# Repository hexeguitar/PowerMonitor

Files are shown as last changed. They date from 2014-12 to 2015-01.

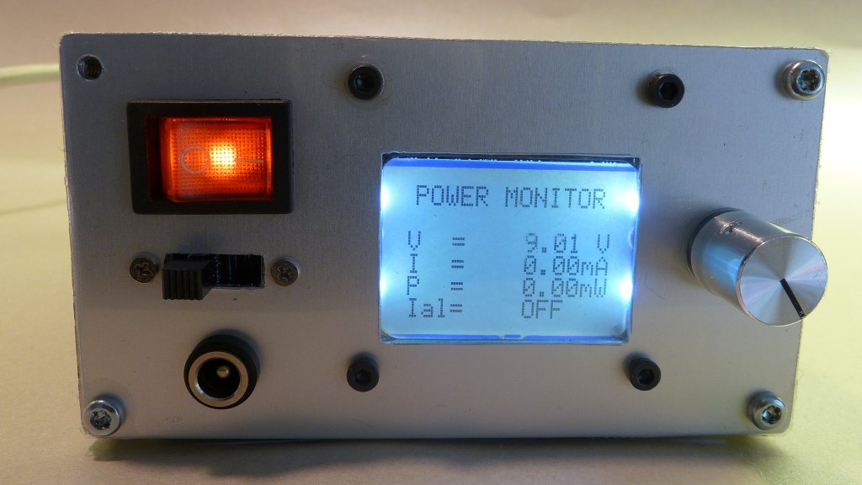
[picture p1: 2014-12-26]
Pics/pmon7.jpg

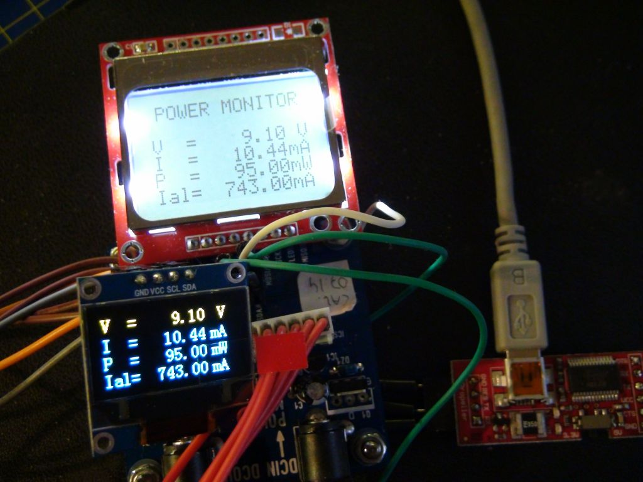
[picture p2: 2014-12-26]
Pics/pmon5.jpg

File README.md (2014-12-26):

#POWER MONITOR

INA219 + PIC24F16KA101 DC voltage, current and power measurement module.

Power Monitor is a small module designed to be placed between the DC power supply and the load. 
It measures the bus voltage, current drawn by the load and calculates the total power consumption.
The results are displayed on a small 0.96" OLED display (SSD1306 controlled via I2C) or
on a SPI controlled PCD5844 (Nokia 5110) LCD.

In addition, the module has an overcurrent alarm feature. A pot is used to set the threshold value (0-1A).
If the measured current exceedes the set threshold, the module will signal it with a pulsing piezo buzzer sound
and a blinking current value on the display.

Since the device was originally designed as an aid while developing guitar effect pedals 
the DC jacks polarity is center negative and the measured current range is set to 0 - 1A.

The device automatically detects if the power jacks are reversed (power applied to the DC out jack)
and kindly asks you to 

###Specs:
- maximum input/bus voltage: 26V DC (INA219B max rating)
- voltage measurement resolution: 10mV 
- measured current range: 0 - 1A (can be changed, refer to the INA219 datasheet)
- current measurement resolution: 50µA
- I alarm range: 0 - 1A, setting the pot to max switches the alarm function OFF
- low dropout reverse supply polarity included
- DC in, DC out jacks: 5.5/2.1mm, center negative
- optional INA219 recalibration mode via UART

###Data outputs:
- SSD1206 OLED display (software I2C)
- PCD8544 LCD (SPI)
- UART (9600 baud)

###Extras:
- hardware I2C pin header
- software I2C pin header (used to driver the OLED display)
- hardware SPI pin header (used to drive the PCD8544 LCD display)
- hardware UART pin header
- ICSP programming pin header
- logic input RB1 

###UART (9600 baud 8b 1Sb NP) commands
NORMAL MODE:

- **lcd**     data output format, copy of the LCD display
- **raw**     data output format, raw numbers separated by semicolons 
- **stop**    stops updating the data via UART
- **start**   start/resume the data update in 1 second intervals
- **rstcnt**  resets the measurement counter to 0
- **getcnt**  returns the actual masurement counter value
- **calrst**  resets the INA219 calibration constant to theoretic calculated stock value (8192)
- **recal**   INA219 secodary recalibration mode used to increase the precision. Requires a separate at least 4.5 digit mA/A meter as a reference
- **getcal**  return the actual INA219 calibration constant value
- **y**       yep! I confirm
- **n**       no, thanks.

RECAL MODE:

- **xxxx.xx** waits for the reference current value (xxxx.xx[mA] format)
- **exit**    cancel the calibration and return to NORMAL mode

The PCB is designed as a small PIC24F16KA101 dev board and could be used to develop many new projects.
I2C, SPI and UART pins are provided as pin headers for easy interfacing.

License: design is released under

Creative Commons NonCommercial-ShareAlike

CC BY-NC-SA



Please contact me for commercial opportunities. 

(c) 07.2014 Piotr Zapart
www.hexeguitar.com

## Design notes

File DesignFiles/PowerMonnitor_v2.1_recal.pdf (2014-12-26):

Project Name:

Author:

## POWER MONITOR

PIOTR ZAPART
www.hexeguitar.com

PIC24F16KA101 + INA219
mini dev board

License:

Date:
05-07.2014

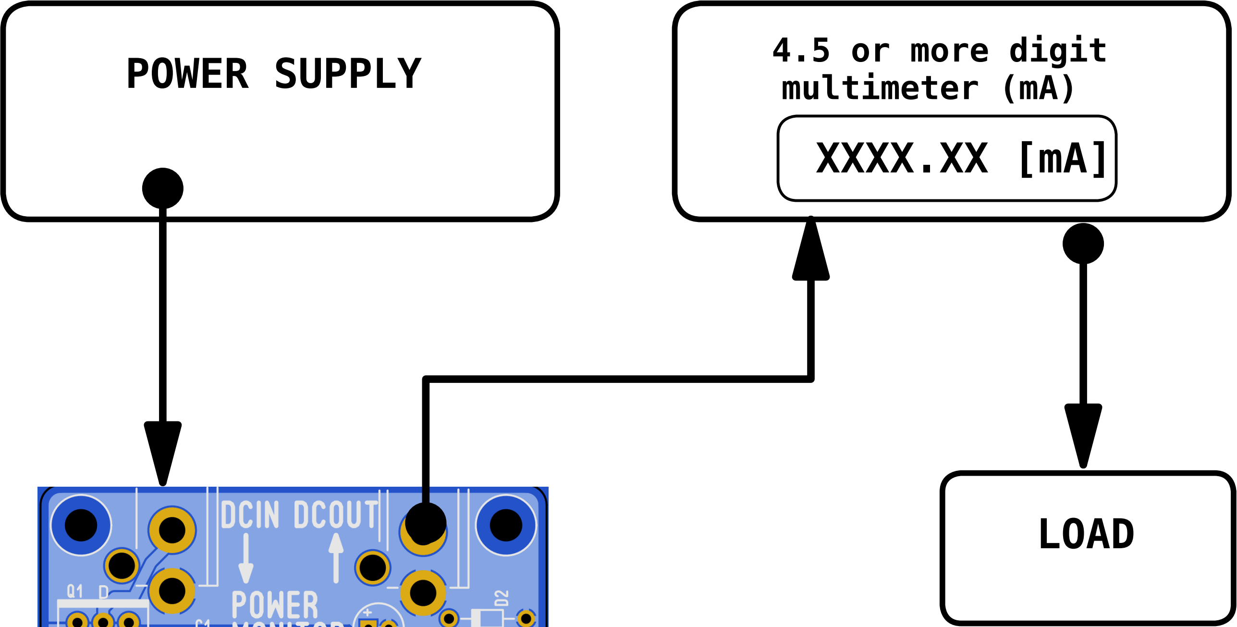
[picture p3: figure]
POWER SUPPLY; LOAD; 4.5 or more digit multimeter (mA) XXXX.XX [mA]

## UART->USB adapter

TX&RX crossed!

PC+serial port terminal

1. Connect the power supply (5-26VDC) to the DCIN input.

### 2. A 4.5 or more digit multimeter (miliAmpmeter) should be

used as a reference. Connect it between the DCOUT and the LOAD.

3. Connect ther UART output (9600baus, 8bit, 1 stop bit,
no parity) to the PC, use an UART/USB adapter if your PC doesn't have the serial port.
4. Use a serial port terminal program to perform the procedure.

### 5. Send the command: "recal" to start the procedure

6. Read the reference current measured with the multimeter.

### 7. Input the refernce current in format xxxx.xx

the value is in [mA].

8. A new calibration constant will be calculated and shown.

### 9. Send "y" to save the new constant in EEPROM or "n"

to cancel the operation.

### 10. You can cancel the recalibration procedure at any time

by sending the command "exit"

## INA219 recalibration procedure via UART

optional way to increase the measurement precision

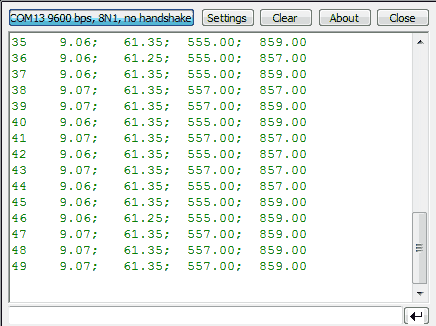
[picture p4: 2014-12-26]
Pics/pmon_uart_raw.png

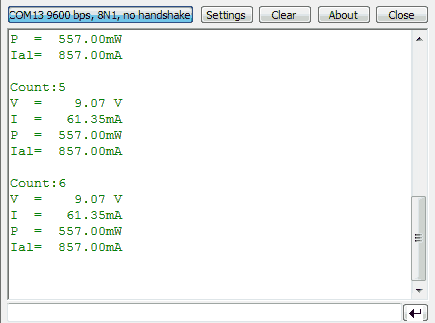
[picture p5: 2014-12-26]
Pics/pmon_uart_lcd.png

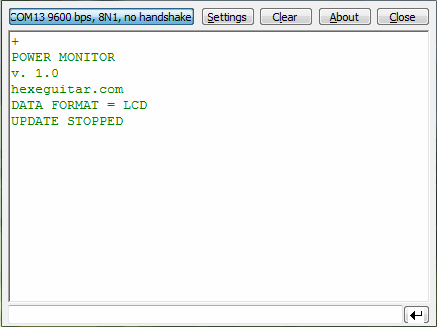
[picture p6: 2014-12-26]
Pics/pmon_uart_startup.png

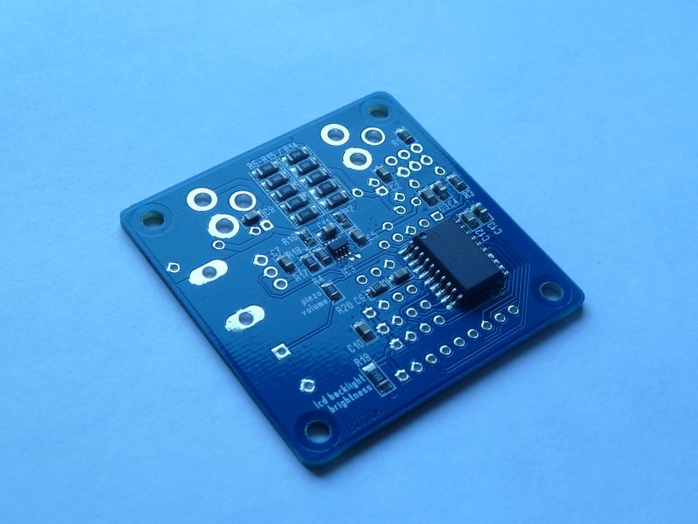
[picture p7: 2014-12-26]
Pics/pmon9.jpg

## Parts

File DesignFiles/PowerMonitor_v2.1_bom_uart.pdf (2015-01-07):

Project Name:

Author:

# POWER MONITOR

## PIOTR ZAPART www.hexeguitar.com

PIC24F16KA101 + INA219
mini dev board

License:

Date:
05-07.2014

BOM:

C1 = 100n (50V 0805)
C2 = 100n (50V 0805)
C3 = 10µ (50V RM2.5/5mm)
C4 = 100n (50V 0805)
C5 = 10µ (16V 0805 MLCC)
C6 = 100n (50V 0805)
C7 = 100n (50V 0805)
C8 = 1µ (0805 16V -do not mount) C9 = 10µ (50V RM2.5/5mm)
C10 = 100n (50V 0805)
C11 = 100n (50V 0805)
C12 = 10µ (16V 0805 MLCC)

CN1 = DCIN (DC Jack 5.5/2.1mm)
CN2 = ICSP (5pin Microchip ICSP) CN3 = DCOUT (DC Jack 5.5/2.1mm)
CN4 = OLED_I2C (4 pin header RM2.54) CN5 = I2C (4 pin header RM2.54)
CN6 = UART (4 pin header RM2.54)
CN7 = SPI/5110 LCD (9 pin header RM2.54) CN8 = RB1 (3 pin header RM2.54)
CN9 = UART (4 pin header RM2.54)

R1 = 100k (0805)
R2 = 470R (0805 1% 0.125W)
R3 = 10k (0805 1% 0.125W)
R4 = 0.1R 1W 0.1% (1206 0.25W 0.5%) R5 = 1R 0.5% (1206 0.25W 0.5%)
R6 = 1R 0.5% (1206 0.25W 0.5%)
R7 = 1R 0.5% (1206 0.25W 0.5%)
R8 = 1R 0.5% (1206 0.25W 0.5%) R9 = 1R 0.5% (1206 0.25W 0.5%) R10 = 1R 0.5% (1206 0.25W 0.5%) R11 = 1R 0.5% (1206 0.25W 0.5%) R12 = 1R 0.5% (1206 0.25W 0.5%) R13 = 1R 0.5% (1206 0.25W 0.5%) R14 = 1R 0.5% (1206 0.25W 0.5%) R15 = 0R(10R) (0805 1% 0.125W) R16 = 0R(10R) (0805 1% 0.125W) R17 = 2k2 (0805 1% 0.125W)
R18 = 2k2 (0805 1% 0.125W) R19 = 47R (1206 0.25W )
R20 = 10k (0805 1% 0.125W)

D1 = 1N4007
D2 = 1N4007

DZ1 = 9V1 (9.1V Zener Diode THT)

IC1 = L78L33 (TO92 3.3V Vreg) IC2 = PIC24F16KA101
IC3 = INA219B SOT23-8

LCD1 = 128x64 i2C SSD1306 OLED
LCD2 = Nokia5110 PCD8544 LCD (SPI)

SPK1 = Piezo buzzer (2.4kHz 12mm RM6.5mm)

P1 = 10k-50k LIN (ALPS RK09L114001T)

Q1 = AP4435GJ (PMOS -30V 21mOhm)

UART (9600 baud 8b 1Sb NP) commands
NORMAL MODE:
lcd | data output format, copy of the LCD display
raw | data output format, raw numbers separated by semicolons
stop | stops updating the data via UART
start | start/resume the data update in 1 second intervals
rstcnt resets the measurement counter to 0
getcnt returns the actual masurement counter value
calrst resets the INA219 calibration constant to theoretic calculated stock value (8192)
recal | INA219 secodary recalibration mode used to increase the precision.
| Requires a separate at least 4.5 digit mA/A meter as a reference.
getcal return the actual INA219 calibration constant value
y | yep! I confirm
n | no, thanks.

RECAL MODE:
xxxx.xx waits for the reference current value (xxxx.xx[mA] format) exit cancel the calibration and return to NORMAL mode

C13 = 100n (50V 0805)

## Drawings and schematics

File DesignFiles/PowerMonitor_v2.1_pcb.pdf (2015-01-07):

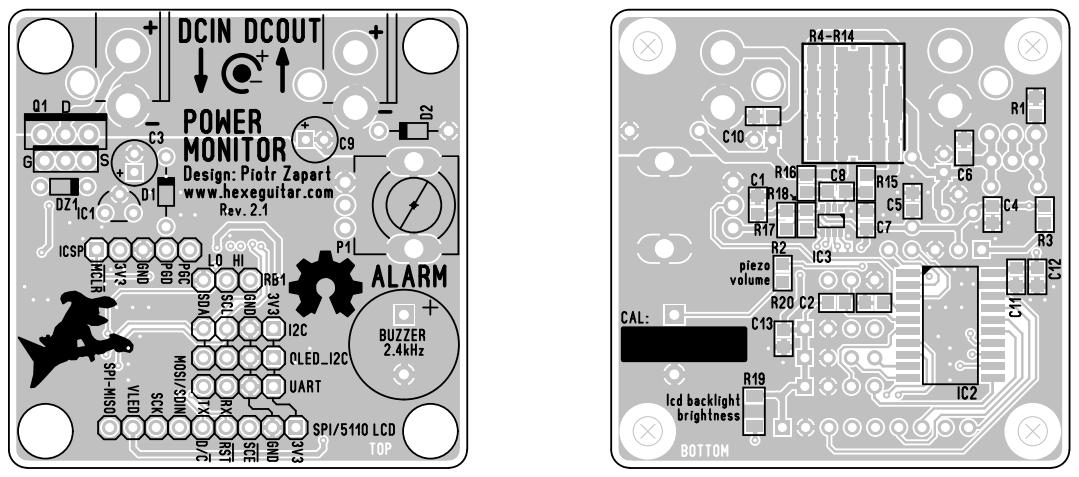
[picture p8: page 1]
Author:; License:; Date: 05-07.2014

Project Name:
POWER MONITOR
PIC24F16KA101 + INA219
mini dev board
PIOTR ZAPART
www.hexeguitar.com

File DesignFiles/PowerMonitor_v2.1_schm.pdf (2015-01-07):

CN1

## DCIN

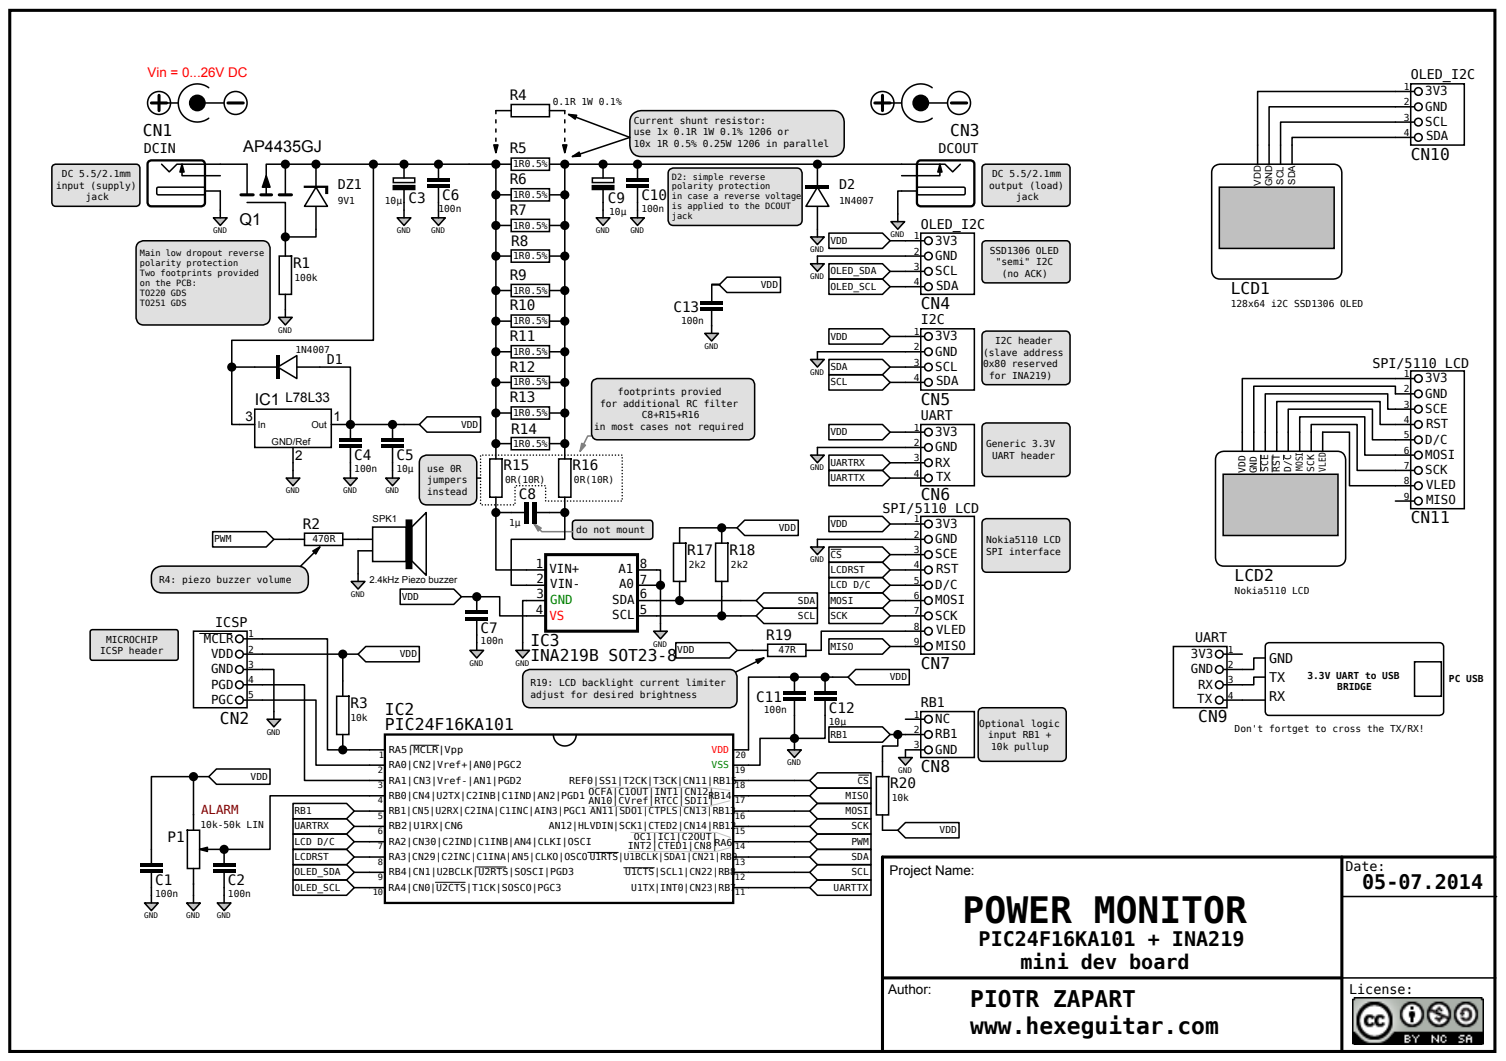
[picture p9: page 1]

in case a reverse voltage
is applied to the DCOUT

Main low dropout reverse
polarity protection
Two footprints provided
on the PCB:
TO220 GDS
TO251 GDS

footprints provied
for additional RC filter

in most cases not required

Don't fortget to cross the TX/RX!

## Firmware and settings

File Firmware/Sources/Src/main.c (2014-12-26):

/*
**                        POWER MONITOR
**                   (c) 07.2014 Piotr Zapart
**                      www.hexeguitar.com
**
**********************************************************************/

#include <xc.h>


_FOSCSEL(FNOSC_FRCDIV);			// Select 8 MHz FRC oscillator with divide-by-N (FRCDIV)


_FOSC (	FCKSM_CSECMD & 			// Enable Clock Switching
	OSCIOFNC_ON &			// Clock output = digital IO
	POSCMOD_NONE );			// Primay osc disable

_FWDT (	FWDTEN_OFF &			//watchdog on
	FWPSA_PR32 &			//prescaler /32
	WDTPS_PS2048 );			//postscaler /2048

_FPOR ( BOREN_BOR3 &                    //Brown-out Reset enabled in hardware; SBOREN bit disabled
        PWRTEN_ON &                     //PWRT enabled
        BORV_V27                        //Brown-out Reset set to Highest Voltage (2.7V)
                    );
_FDS    (DSWDTEN_OFF);                   //DSWDT disabled

_FICD (ICS_PGx2);

#include "platform.h"


// ################ FUNCTION DEFINITIONS ##################


/// ### Ialarm calculation ###
uint16_t calc_Ialarm(uint16_t input, uint16_t max)
{
    uint32_t temp32;
    uint16_t temp16;

    temp32 = __builtin_muluu(input,input);      //square for better resolutionx
    temp16 = (uint16_t)(temp32>>10);            //settings

    temp32 = __builtin_muluu(temp16,(max+5));   //scale it 0...IalMax+5
    temp16 = (uint16_t)((temp32>>10)+1);
    
    if (temp16 > max)   return 0;       //Ial = 0 -> alarm shutdown
   // else                return myround((float)temp16);
    else                return temp16;
}

void wait8ms(unsigned int cnt)
{
	delay8ms = cnt;
	while(delay8ms);
}
// ################## DISPLAY DATA ##########################
void display_data(cal_modes cal_mode)
{
        char temp_txt[9];
	static uint8_t blinker;
	blinker++;
        //convert and format float values to ascii    
        f_to_txt(bus_voltage_V,V_txt);
        f_to_txt(current_mA,I_txt);
        
        //convert and format int values to ascii
        int_to_txt(power_mW,4,P_txt);
        int_to_txt(Ialarm,4,Ial_txt);

        switch(cal_mode)
        {
            case CL_OFF:
                      //update OLED display
                        OLED_char_F8x16(0,0,vbus_txt,NORMAL);
                        OLED_char_F8x16(100,0,volts_txt,NORMAL);
                        OLED_char_F8x16(32,0,V_txt,NORMAL);
                        OLED_char_F8x16(0,2,current_txt,NORMAL);
                        OLED_char_F8x16(32,2,I_txt,(status.alarm&&(blinker&_BV(0))));
                        OLED_char_F8x16(100,2,mA_txt,NORMAL);
                        OLED_char_F8x16(0,4,power_txt,NORMAL);
                        OLED_char_F8x16(32,4,P_txt,NORMAL);
                        OLED_char_F8x16(100,4,mW_txt,NORMAL);
                        OLED_char_F8x16(0,6,curr_al_txt,NORMAL);
                        if (status.alarm_sdown)
                        {
                            OLED_char_F8x16(32,6,off_txt,NORMAL);
                            OLED_char_F8x16(100,6,"  ",NORMAL);
                        }
                        else
                        {
                            OLED_char_F8x16(32,6,Ial_txt,NORMAL);
                            OLED_char_F8x16(100,6,mA_txt,NORMAL);
                        }
                        //update 5110 display
                        LCD5110_write_string(3,0,"POWER MONITOR",DISP_NORMAL);
                        LCD5110_write_string(0,2,vbus_txt,DISP_NORMAL);
                        LCD5110_write_string(72,2,volts_txt,DISP_NORMAL);
                        LCD5110_write_string(24,2,V_txt,DISP_NORMAL);
                        LCD5110_write_string(0,3,current_txt,DISP_NORMAL);
                        LCD5110_write_string(24,3,I_txt,(status.alarm&&(blinker&_BV(0))));
                        LCD5110_write_string(72,3,mA_txt,DISP_NORMAL);
                        LCD5110_write_string(0,4,power_txt,DISP_NORMAL);
                        LCD5110_write_string(24,4,P_txt,DISP_NORMAL);
                        LCD5110_write_string(72,4,mW_txt,DISP_NORMAL);
                        LCD5110_write_string(0,5,curr_al_txt,DISP_NORMAL);
                        if (status.alarm_sdown)
                        {
                            LCD5110_write_string(24,5,off_txt,DISP_NORMAL);
                        }
                        else
                        {
                            LCD5110_write_string(24,5,Ial_txt,DISP_NORMAL);
                            LCD5110_write_string(72,5,mA_txt,DISP_NORMAL);
                        }
                        break;
            case CL_RST:
                        
            case CL_RST_CONFIRM:
                        OLED_char_F8x16(16,0,cal_txt,NORMAL);
                        OLED_char_F8x16(32,2,rst_txt,NORMAL);
                        OLED_char_F8x16(0,6,save_txt,NORMAL);
                        OLED_char_F8x16(48,6,yn_txt,NORMAL);
                        LCD5110_write_string(8,0,cal_txt,DISP_NORMAL);
                        LCD5110_write_string(18,2,rst_txt,DISP_NORMAL);
                        LCD5110_write_string(0,5,save_txt,DISP_NORMAL);
                        LCD5110_write_string(30,5,yn_txt,DISP_NORMAL);
                        break;
            case RCL_ON:
                        OLED_char_F8x16(16,0,cal_txt,NORMAL);
                        OLED_char_F8x16(0,2,current_txt,NORMAL);
                        OLED_char_F8x16(32,2,I_txt,NORMAL);
                        OLED_char_F8x16(100,2,mA_txt,NORMAL);
                        OLED_char_F8x16(0,4,iref_txt,NORMAL);
                        OLED_char_F8x16(32,4,he_txt,(blinker&_BV(0)));
                        OLED_char_F8x16(100,4,mA_txt,NORMAL);
                        LCD5110_write_string(12,0,cal_txt,DISP_NORMAL);
                        LCD5110_write_string(0,2,current_txt,DISP_NORMAL);
                        LCD5110_write_string(24,2,I_txt,NORMAL);
                        LCD5110_write_string(72,2,mA_txt,DISP_NORMAL);
                        LCD5110_write_string(0,3,iref_txt,DISP_NORMAL);
                        LCD5110_write_string(24,3,he_txt,(blinker&_BV(0)));
                        LCD5110_write_string(72,3,mA_txt,DISP_NORMAL);
                        break;
            case RCL_CONFIRM:
                        
                        f_to_txt(ref_current_mA,temp_txt);
              
                        OLED_char_F8x16(16,0,cal_txt,NORMAL);

                        OLED_char_F8x16(0,2,current_txt,NORMAL);
                        OLED_char_F8x16(32,2,I_txt,NORMAL);
                        OLED_char_F8x16(100,2,mA_txt,NORMAL);
                        OLED_char_F8x16(0,4,iref_txt,NORMAL);
                        OLED_char_F8x16(32,4,temp_txt,NORMAL);
                        OLED_char_F8x16(100,4,mA_txt,NORMAL);
                        OLED_char_F8x16(0,6,save_txt,NORMAL);
                        OLED_char_F8x16(48,6,yn_txt,NORMAL);

                        LCD5110_write_string(12,0,cal_txt,DISP_NORMAL);
                        LCD5110_write_string(0,2,current_txt,DISP_NORMAL);
                        LCD5110_write_string(24,2,I_txt,NORMAL);
                        LCD5110_write_string(72,2,mA_txt,DISP_NORMAL);
                        LCD5110_write_string(0,3,iref_txt,DISP_NORMAL);
                        LCD5110_write_string(24,3,temp_txt,NORMAL);
                        LCD5110_write_string(72,3,mA_txt,DISP_NORMAL);
                        LCD5110_write_string(0,5,save_txt,DISP_NORMAL);
                        LCD5110_write_string(30,5,yn_txt,DISP_NORMAL);
                        break;          
        }       
}
// ################## DISPLAY WARNING #######################
void display_warning(void)
{
	static uint8_t blinker;
	blinker++;
	OLED_char_F8x16(20,0,warning1_txt,NORMAL);
	OLED_char_F8x16(32,2,warning2_txt,(blinker&_BV(0)));
	OLED_char_F8x16(44,4,warning3_txt,NORMAL);
	OLED_char_F8x16(0,6,warning4_txt,NORMAL);
        OLED_char_F8x16(32,6,warning5_txt,NORMAL);

        LCD5110_write_string(8,0,warning1_txt,DISP_NORMAL);
        LCD5110_write_string(15,2,warning2_txt,(blinker&_BV(0)));
        LCD5110_write_string(13,4,warning3_txt,DISP_NORMAL);
        LCD5110_write_string(49,4,warning4_txt,DISP_NORMAL);
        LCD5110_write_string(8,5,warning5_txt,DISP_NORMAL);

}
// ################## SEND RESULTS VIA UART #######################
uart_data_format get_udata_format(void)
{
    uart1.setup_eep =  eeRead(UART_SETUP_EEP_ADDR);

    if (uart1.setup_eep&_BV(U1_DISP_MODE))
    {
        UART1_send_string_ln(format_raw_txt);
        return RAW;
    }
    else
    {
        UART1_send_string_ln(format_lcd_txt);
        return LCD;
    }
}
void update_uart(uart_data_format mode)
{
    char uart_cnt_txt[9];

    itoa(uart_cnt_txt, (int)uart1.counter, 10);

    uart1.counter++;
    switch(mode)
    {
        case OFF:   break;
        case LCD:
                    UART1_send_string("Count:");
                    UART1_send_string_ln(uart_cnt_txt);
                    UART1_send_string(vbus_txt);
                    UART1_send_string(V_txt);
                    UART1_send_string_ln(volts_txt);
                    UART1_send_string(current_txt);
                    UART1_send_string(I_txt);
                    UART1_send_string_ln(mA_txt);
                    UART1_send_string(power_txt);
                    UART1_send_string(P_txt);
                    UART1_send_string_ln(mW_txt);
                    UART1_send_string(curr_al_txt);
                    if (status.alarm_sdown)
                    {
                        UART1_send_string(off_txt);
                    }
                    else
                    {
                        UART1_send_string(Ial_txt);
                        UART1_send_string(mA_txt);
                    }
                    UART1_send_string("\n");
                    break;
        case RAW:
                    UART1_send_string(uart_cnt_txt);
                    UART1_send_string(V_txt);
                    UART1_send_string(sep_char);
                    UART1_send_string(I_txt);
                    UART1_send_string(sep_char);
                    UART1_send_string(P_txt);
                    UART1_send_string(sep_char);
                    if (status.alarm_sdown)
                    {
                        UART1_send_string(off_txt);
                    }
                    else
                    {
                        UART1_send_string(Ial_txt);
                    }
                    break;
    }
}

// ### send reverse power jacks warning ####
void uart_warning(void)
{
    UART1_send_string(warning1_txt);
    UART1_send_string(" ");
    UART1_send_string_ln(warning2_txt);
    UART1_send_string(warning3_txt);
    UART1_send_string(" ");
    UART1_send_string(warning4_txt);
    UART1_send_string(" ");
    UART1_send_string_ln(warning5_txt);
}
// ### decode incoming UART commands ###
uint8_t decode_char(uint16_t err_data)
{
    char data;
    static uint8_t data_complete;
    uint8_t eep_changed = 0;

    if (err_data == UART_NO_DATA)    return 0;

    status.error = (err_data&0xFF00)>>8;
    data = (char) (err_data&0x00FF);

    cmd_buffer[cmdbuf_index++] = data;

    if (data=='\n')
    {
        data_complete = 1;
    }

    if (cmdbuf_index>8) cmdbuf_index = 0;
    
    
    if (data_complete)    
    {

            switch (status.cal_mode)
            {
                case CL_OFF:
                            if (!strncmp(cmd_buffer,"lcd",3))
                            {
                                if (uart1.format != LCD)
                                {
                                    uart1.format = LCD;
                                    uart1.setup_eep = 0;
                                    eep_changed |= _BV(U1_DISP_MODE);
                                }

                                UART1_send_string(format_lcd_txt);
                                flush_cmd_buff();
                            }
                            if (!strncmp(cmd_buffer,"raw",3))
                            {
                                if(uart1.format != RAW)
                                {
                                    uart1.format = RAW;
                                    uart1.setup_eep = 1;
                                    eep_changed |= _BV(U1_DISP_MODE);
                                }
                                UART1_send_string(format_raw_txt);
                                flush_cmd_buff();
                            }
                            if (!strncmp(cmd_buffer,"stop",4))
                            {
                                uart1.updater = 0;
                                UART1_send_string("UART UPDATE STOP");
                                flush_cmd_buff();
                            }
                            if (!strncmp(cmd_buffer,"start",5))
                            {
                                uart1.updater = 1;
                                UART1_send_string("UART UPDATE START");
                                flush_cmd_buff();
                            }
                           if (!strncmp(cmd_buffer,"rstcnt",5))
                            {
                                uart1.counter = 0;
                                UART1_send_string("RESET COUNTER");
                                flush_cmd_buff();
                            }
                           if (!strncmp(cmd_buffer,"getcnt",6))
                            {
                                itoa(cmd_buffer, (int)(uart1.counter), 10);
                                UART1_send_string("COUNTER VALUE = ");
                                UART1_send_string(cmd_buffer);
                                flush_cmd_buff();
                            }
                            if (!strncmp(cmd_buffer,"calrst",6))
                            {
                                OLED_fill_screen(0x00);      //cls OLED
                                LCD5110_clear();            //cls LCD
                                status.cal_mode = CL_RST;
                                UART1_send_string_ln("INA219 Calibration mode");
                                UART1_send_string_ln("Restore to default value: 8192");
                                UART1_send_string(save_txt);
                                UART1_send_string_ln(yn_txt);
                                status.cal_mode = CL_RST_CONFIRM;
                                flush_cmd_buff();
                            }
                            if (!strncmp(cmd_buffer,"recal",5))
                            {
                                OLED_fill_screen(0x00);      //cls OLED
                                LCD5110_clear();            //cls LCD
                                status.cal_mode = RCL_ON;
                                UART1_send_string_ln("INA219 REcalibration mode");
                                UART1_send_string_ln("(type exit to cancel)");
                                UART1_send_string_ln(enter_I_txt);
                                flush_cmd_buff();
                            }
                            break;

                case RCL_ON:
                                    // exit command, calibration cancel
                                    if (!strncmp(cmd_buffer,"exit",4))
                                    {
                                        OLED_fill_screen(0x00);      //cls OLED
                                        LCD5110_clear();            //cls LCD
                                        status.cal_mode = CL_OFF;
                                        UART1_send_string_ln("INA219 Recalibration");
                                        UART1_send_string_ln("cancelled");
                                        flush_cmd_buff();
                                        break;
                                    }

                                    //wait for refernce current
                                    ref_current_mA = atof(cmd_buffer);
                                    if (ref_current_mA && (ref_current_mA<=MAX_I_ALARM))
                                    {
                                       f_to_txt(ref_current_mA,cmd_buffer);
                                       UART1_send_string(iref_txt);
                                       UART1_send_string(cmd_buffer);
                                       UART1_send_string_ln(mA_txt);
                                       ina219_calValue_new = calc_new_cal( ref_current_mA,
                                                                current_mA,
                                                                ina219_calValue);
                                       itoa(cmd_buffer, (int)ina219_calValue, 10);
                                       UART1_send_string(old_txt);
                                       UART1_send_string(inacal_txt);
                                       UART1_send_string_ln(cmd_buffer);

                                       itoa(cmd_buffer, (int)ina219_calValue_new, 10);
                                       UART1_send_string(new_txt);
                                       UART1_send_string(inacal_txt);
                                       UART1_send_string_ln(cmd_buffer);
                                       UART1_send_string(save_txt);
                                       UART1_send_string_ln(yn_txt);
                                       status.cal_mode = RCL_CONFIRM;
                                    }
                                    else
                                    {
                                        UART1_send_string(error_txt);
                                        UART1_send_string(iref_txt);
                                        UART1_send_string_ln(err_oor_txt);
                                    }
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
int main(void)
{
   startup();

   while(1)
   {
        ClrWdt();

        wait8ms(8);		//INA219 averaging time

        current_mA = INA219_getCurrent_mA();
        bus_voltage_V = INA219_getBusVoltage_V();
        power_mW = INA219_getPower_mW();

        Ialarm = calc_Ialarm(Ialarm_adc, MAX_I_ALARM);

        // check if the alarm is switched on
        if (Ialarm)     status.alarm_sdown = 0;
        else            status.alarm_sdown = 1;
        // check if the current > set threshold
        if ((current_mA > Ialarm) && !status.alarm_sdown)
                        status.alarm = 1;
        else		status.alarm = 0;

        if(current_mA < -2.0) // negative current, jacks reversed!!!
        {
            display_warning();
            status.pwr_rev = 1;
            uart1.updater = 1;
        }
        else
        {
            display_data(status.cal_mode);
            status.pwr_rev = 0;
        }
        if (uart1.updater && !(uart1.update_clock))
        {
            if (status.pwr_rev) uart_warning();
            else                update_uart(uart1.format);
            uart1.update_clock = UART_UPDATE_RATE_MS;
        }
        // check if there is anything in the UART RX buffer
        decode_char(UART1_get_char());

   }    // loop end
}       //main end

// ###########################################################
// ######################### ISRs ############################
// ###########################################################


// ###### ADC ######
void __attribute__((interrupt,no_auto_psv)) _ADC1Interrupt( void )
{
	IFS0bits.AD1IF = 0;			//clear flag
	static volatile uint32_t avg;           //simple lowpass filter
	avg -= avg>>8;
	avg += ADC1BUF0+1;
	Ialarm_adc = (uint16_t) (avg>>8);
}

// ################## TIMER 3 Interrupt #######################
/*
	8ms 
	delays, beeper pulses
*/

void __attribute__((interrupt,no_auto_psv)) _T3Interrupt( void )
{
	IFS0bits.T3IF = 0;					  //clear flag
	uint16_t temp16;
	
	temp16 = delay8ms;
	if (temp16) temp16--;
	delay8ms = temp16;

        temp16 = uart1.update_clock;
        if (temp16) temp16--;
        uart1.update_clock = temp16;
	
	temp16 = beeper;
	temp16++;
	if ((temp16 & _BV(6)) && (status.alarm || status.pwr_rev))
		BUZZER = BUZZER_ON;
	else    BUZZER = BUZZER_OFF;
	
	beeper = temp16;
}

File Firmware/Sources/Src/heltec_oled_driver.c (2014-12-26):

/*
 * heltec_oled_driver.c
 *
 *  Created on: 30.03.2014
 *      Author: Pio
 *
 * Based on the heltec OLED Arduino library
 */
#include <xc.h>
//#include <p24F16KA101.h>
#include <libpic30.h>
#include <stdlib.h>
#include <string.h>  
#include "stdint.h"
#include "heltec_oled_driver.h"
#include "fonts.h"


void OLED_start(void)
{
  OLED_SCL_HI();
  OLED_SDA_HI();
  wait_nop(OLED_I2C_DLY);
  OLED_SDA_LO();
  wait_nop(OLED_I2C_DLY);

  OLED_SCL_LO();
  wait_nop(OLED_I2C_DLY);
}

void OLED_stop(void)
{
  OLED_SDA_LO();
  wait_nop(OLED_I2C_DLY);
  OLED_SCL_HI();
  wait_nop(OLED_I2C_DLY);
  OLED_SDA_HI();
  wait_nop(OLED_I2C_DLY);
}

void OLED_write_byte(uint8_t oled_Byte)
{
  uint8_t i;
  for(i=0;i<8;i++)
  {
    if((oled_Byte << i) & 0x80)
    	{
            OLED_SDA_HI();
    	}
    else
    	{
            OLED_SDA_LO();
    	}
    wait_nop(OLED_I2C_DLY);
    OLED_SCL_HI();
    wait_nop(OLED_I2C_DLY);
    OLED_SCL_LO();
    wait_nop(OLED_I2C_DLY);
   }
   OLED_SDA_HI();
   wait_nop(OLED_I2C_DLY);
   OLED_SCL_HI();
   wait_nop(OLED_I2C_DLY);
   OLED_SCL_LO();
   wait_nop(OLED_I2C_DLY);
}

void OLED_write_command(uint8_t oled_Command)
{
   OLED_start();
   OLED_write_byte(0x78);         //Slave address,SA0=0
   OLED_write_byte(0x00);	  //write command
   OLED_write_byte(oled_Command);
   OLED_stop();
}

void OLED_begin_data(void)
{
   OLED_start();
   OLED_write_byte(0x78);
   OLED_write_byte(0x40);	//write data
}

//Set the starting point coordinates
void OLED_SetPos(uint8_t x, uint8_t y)
{
  OLED_start();
  OLED_write_byte(0x78);  //Slave address,SA0=0
  OLED_write_byte(0x00);	//write command

  OLED_write_byte(0xB0 + y);
  OLED_write_byte(((x & 0xF0)>>4)|0x10);
  OLED_write_byte((x & 0x0F)|0x01);

  OLED_stop();
}

void OLED_fill_screen(uint8_t fill_Data)
{
  uint8_t m,n;
  for(m=0;m<8;m++)
  {
    OLED_write_command(0xB0 + m);	//page0-page1
    OLED_write_command(0x00);		//low column start address
    OLED_write_command(0x10);		//high column start address
    OLED_begin_data();
    for(n=0;n<128;n++)
    {
      OLED_write_byte(fill_Data);
    }
    OLED_stop();
  }
}


//ASCII character display 8x8
/*
void Char_H8x8(uint8_t x, uint8_t y, const uint8_t ch[])
{
  uint8_t c,i,j=0;
  while(ch[j] != '\0')
  {
    c = ch[j] - 32;
    if(x>120)
    {
      x=0;
      y++;
    }
    oled_SetPos(x,y);
    OLED_begin_data();
    for(i=0;i<8;i++)
    {
    	OLED_write_byte(fontH8x8[c][i]);
	}
    oled_Stop();
    x += 8;
    j++;
  }
}

*/

/*
void Char_H6x8(uint8_t x, uint8_t y, const uint8_t ch[])
{
  uint8_t c,i,j=0;
  while(ch[j] != '\0')
  {
    c = ch[j];// - 32;
    if(x>126)
    	{
     	 	x=0;
      		y++;
    	}
    oled_SetPos(x,y);
    OLED_begin_data();
    for(i=0;i<6;i++)
    	{
	    OLED_write_byte(fontH6x8[c][i]);
    	}
    oled_Stop();
    x += 6;
    j++;
  }
}
*/

void OLED_char_F8x16(uint8_t x, uint8_t y,const char ch[],uint8_t inv)
{
	uint8_t c=0,i=0,j=0;
	uint8_t out_byte;
	while (ch[j]!='\0')
	{
		c =ch[j]-32;
		if(x>120)
			{
      			x=0;
      			y++;
    		}
		OLED_SetPos(x,y);
		OLED_begin_data();
		for(i=0;i<8;i++)
			{
			if (inv)	out_byte = (font8X16[(c<<4)+i])^0xFF;
	     		else		out_byte = font8X16[(c<<4)+i];
				OLED_write_byte(out_byte);
	   	 	}
	    OLED_stop();
		OLED_SetPos(x,y+1);
		OLED_begin_data();
		for(i=0;i<8;i++)
			{
			if (inv)	out_byte = (font8X16[(c<<4)+i+8])^0xFF;
	     		else		out_byte = font8X16[(c<<4)+i+8];
	    	 	OLED_write_byte(out_byte);
	    	}
	    OLED_stop();
		x+=8;
		j++;
	}
}

void OLED_draw_BMP(uint8_t x0, uint8_t y0, uint8_t x1, uint8_t y1,const uint8_t BMP[])
{
  uint16_t j=0;
  uint8_t x,y;

  if((y1%8)==0)
  {
	  y = y1>>3; //y=y1/8;
  }

  else
  {
	  y = (y1>>3) + 1; //y=y1/8+1;
  }

  for(y=y0;y<y1;y++)
  {
    OLED_SetPos(x0,y);
    OLED_begin_data();
    for(x=x0;x<x1;x++)
    {
      OLED_write_byte(BMP[j++]);
    }
    OLED_stop();
  }
}


//SSD1306 initialization
void OLED_init(void)
{
    // config output pins
    TRISAbits.TRISA4 = 0;           //OLED software I2C SCL
    TRISBbits.TRISB4 = 0;           //OLED software I2C SDA

  OLED_write_command(0xAE);//display off
  OLED_write_command(0x00);//Set Memory Addressing Mode
  OLED_write_command(0x10);//00,Horizontal Addressing Mode;01,Vertical Addressing Mode;10,Page Addressing Mode (RESET);11,Invalid
  OLED_write_command(0x40);//Set Page Start Address for Page Addressing Mode,0-7
  OLED_write_command(0x81);//Set COM Output Scan Direction
  OLED_write_command(0xCF);//---set low column address
  OLED_write_command(0xA1);//---set high column address
  OLED_write_command(0xC8);//--set start line address
  OLED_write_command(0xA6);//--set contrast control register
  OLED_write_command(0xA8);
  OLED_write_command(0x3F);//--set segment re-map 0 to 127
  OLED_write_command(0xD3);//--set normal display
  OLED_write_command(0x00);//--set multiplex ratio(1 to 64)
  OLED_write_command(0xD5);//
  OLED_write_command(0x80);//0xa4,Output follows RAM content;0xa5,Output ignores RAM content
  OLED_write_command(0xD9);//-set display offset
  OLED_write_command(0xF1);//-not offset
  OLED_write_command(0xDA);//--set display clock divide ratio/oscillator frequency
  OLED_write_command(0x12);//--set divide ratio
  OLED_write_command(0xDB);//--set pre-charge period
  OLED_write_command(0x40);//
  OLED_write_command(0x20);//--set com pins hardware configuration
  OLED_write_command(0x02);
  OLED_write_command(0x8D);//--set vcomh
  OLED_write_command(0x14);//0x20,0.77xVcc
  OLED_write_command(0xA4);//--set DC-DC enable
  OLED_write_command(0xA6);//
  OLED_write_command(0xAF);//--turn on oled panel
}

void wait_nop (uint8_t count)
{
    while (count--)
    {
        asm("nop");
    }
}

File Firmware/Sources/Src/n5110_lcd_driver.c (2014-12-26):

/*
        NOKIA 5110 LCD SPI driver

 */
#include <xc.h>
#include <libpic30.h>
#include <stdlib.h>
#include "stdint.h"
#include "n5110_lcd_driver.h"
#include "font6x8.h"


void LCD5110_init(uint8_t contrast)
{
    //Port configuration
//    !CS =       RB15
//    LDCRST =    RA3
//    LCD D/C =   RA2
//    MOSI =      RB13
//    SCK =       RB12
//    MISO =      RB14

    TRISBbits.TRISB15 = PORT_OUT;       //!CS
    TRISAbits.TRISA3 = PORT_OUT;        //LCDRST
    TRISAbits.TRISA2 = PORT_OUT;        //LCD D/C
    TRISBbits.TRISB13 = PORT_OUT;       //MOSI
    TRISBbits.TRISB12 = PORT_OUT;       //SCK
    TRISBbits.TRISB14 = PORT_IN;        // MISO

    if (contrast>0x7F)      contrast=0x7F;
    uint16_t i = 1500;
    LCD_RST = 0;
    while (i--);
    LCD_RST = 1;

    LCD5110_write_byte(PCD8544_FUNCTIONSET | PCD8544_EXTENDEDINSTRUCTION, LCD_CMD);
    LCD5110_write_byte(PCD8544_SETVOP | contrast, LCD_CMD);
    LCD5110_write_byte(PCD8544_SETTEMP | LCD_TEMP, LCD_CMD);
    LCD5110_write_byte(PCD8544_SETBIAS | LCD_BIAS, LCD_CMD);
    LCD5110_write_byte(PCD8544_FUNCTIONSET, LCD_CMD);
    LCD5110_clear();
    LCD5110_write_byte(PCD8544_DISPLAYCONTROL | PCD8544_DISPLAYNORMAL, LCD_CMD);
  }

void LCD5110_write_byte(uint8_t dat, uint8_t dat_type)
  {
    uint8_t dummy;

    SPI_CS = 0;

    if (dat_type == LCD_CMD) LCD_DC = LCD_CMD;
    else                     LCD_DC = LCD_DATA;

    SPI1BUF = dat;					//send byte
    while(SPI1STATbits.SPITBF);                         //wait until transmitted
    while(!SPI1STATbits.SPIRBF);                         //wait for receive Buffer
    dummy = SPI1BUF;

    SPI_CS = 1;
  }

void LCD5110_draw_bmp_pixel(uint8_t X,uint8_t Y,uint8_t *map,
                  uint8_t Pix_x,uint8_t Pix_y)
  {
    uint16_t i,n;
    uint8_t row;

    if (Pix_y%8==0) row=Pix_y/8;
      else
        row=Pix_y/8+1;

    for (n=0;n<row;n++)
      {
      	LCD5110_set_XY(X,Y);
        for(i=0; i<Pix_x; i++)
          {
            LCD5110_write_byte(map[i+n*Pix_x], 1);
          }
        Y++;
      }
  }

void LCD5110_write_string(uint8_t X,uint8_t Y,const char *s, uint8_t mode)
  {
    LCD5110_set_XY(X,Y);
      while (*s)
      {
	 LCD5110_write_char6x8(*s, mode);
	 s++;
      }    


  }


void LCD5110_write_char6x8(char c, uint8_t mode)
{
    uint8_t line;
    uint8_t ch, i;

    i = c - 32;
    for (line=0; line<6; line++)
    {
      ch = font6x8[i][line];
      LCD5110_write_byte( (mode==DISP_NORMAL)? ch: (ch^ 0xff) , LCD_DATA);
    }
}

  void LCD5110_set_XY(uint8_t X, uint8_t Y)
  {
    LCD5110_write_byte(0x40 | Y, LCD_CMD);		// column
    LCD5110_write_byte(0x80 | X, LCD_CMD);          	// row
  }

void LCD5110_clear(void)
  {
    uint16_t i;

    LCD5110_write_byte(PCD8544_SETYADDR, LCD_CMD);
    LCD5110_write_byte(PCD8544_SETXADDR, LCD_CMD);

    for (i=0; i<504; i++)
      LCD5110_write_byte(0, LCD_DATA);
  }
void LCD5110_invert(uint8_t mode)
{

    if (mode)
         LCD5110_write_byte(PCD8544_DISPLAYCONTROL | PCD8544_DISPLAYINVERTED, LCD_CMD);
    else
         LCD5110_write_byte(PCD8544_DISPLAYCONTROL | PCD8544_DISPLAYNORMAL, LCD_CMD);

}
